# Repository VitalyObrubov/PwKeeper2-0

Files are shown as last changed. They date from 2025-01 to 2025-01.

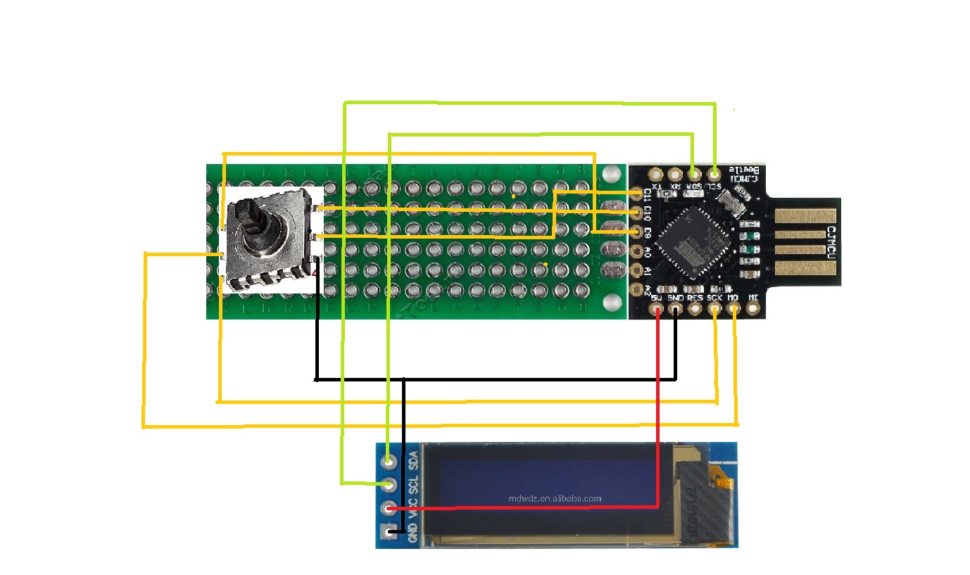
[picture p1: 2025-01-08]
PwKeeper-wiring.jpg

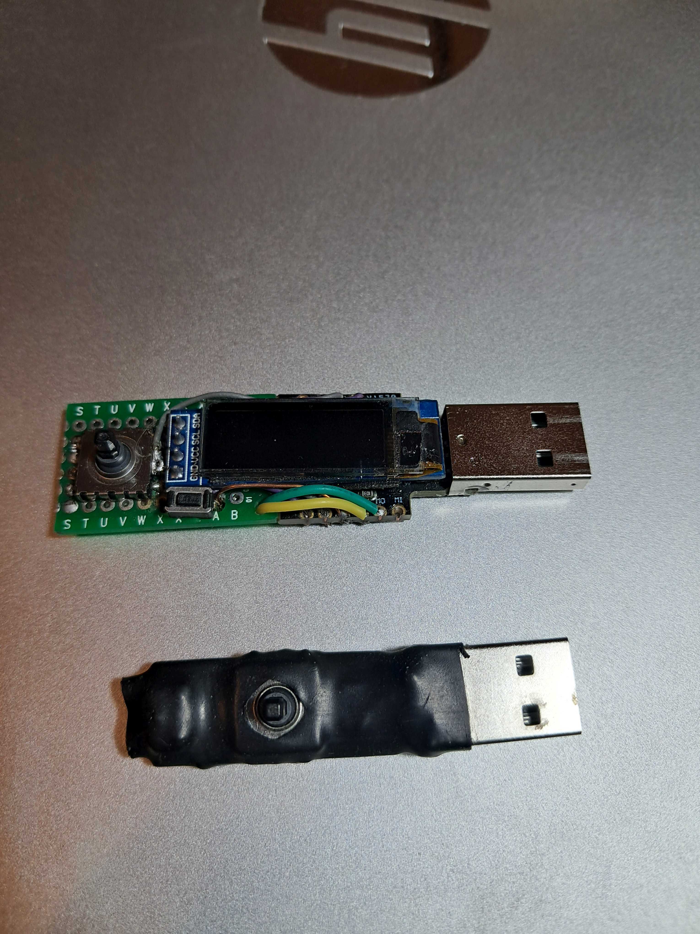
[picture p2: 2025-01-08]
PwKeeper-vs-MemType.jpg

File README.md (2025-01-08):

*****************   PasswordKeeper v2.0   ***********************

This is a simple hand made device for storing your passwords.
Essentially, it emulates USB keyboard and should work with any device where USB keyboard may be connected.
It sends user-defined sequences of keypresses as if they were entered from keyboard.
To simplify password management in token Windows program PwKeeperPC.exe is included into the package.
Also, serial console added to device. It allows config device from *nix systems.

------------------------------------------------------------------
How to write HEX to board:

1) Download and install software from arduino.cc
2) Connect your board to PC and install all necessary drivers.
3) Open DeviceManager window. Open COM and LPT node. There you should see you board as virtual COM port.
4) On Arduino board connect RST pin to GND.
5) In COM and LPT node new COM port should appear on ~8 sec. And then it replaced by port, which you have seen already.
   If you do not see new ports to appear try to repeat step 4, but connect RST to GND 2 times with interval of 1 sec between tries.
6) Replace COM16 in command in CMD file with port, which appears temporarily.
   Check pathes to AVRDUDE.EXE and avrdude.conf in command.
   Correct it according to your system.
7) Connect RST pin to GND. Start CMD and remove RST to GND connection.
   Download to board should pass.

Essentialy, COM port that you see when board is in idle state - it is HID port. It is not the LOADER port. Board LOADER COM appears only on short period after reset.
-------------------------------------------------------------------   

Changes history:
v2.0 - 08.01.2025
        - Forked & changed
	- Arduino Leonardo Beetle insted Leonardo-Pro-Micro-ATmega32U4
 - 4-way joistick insted 2 keys

v1.5 - 13.02.2018
        - Bugfix in login transmit procedure.

v1.4 - 24.11.2016
	- *nix-like TTY console added to PwKeeper
	- Commands description added to rtf.

v1.3 - 16.11.2016
	- Several bugfixes in PwKeeperPC.exe
	- Several bugfixes in PwKeeper.hex
 	- *.stl files added
	- Quick access buttons added to wiring diagram

v1.2 - 10.11.2016 
	- First public release

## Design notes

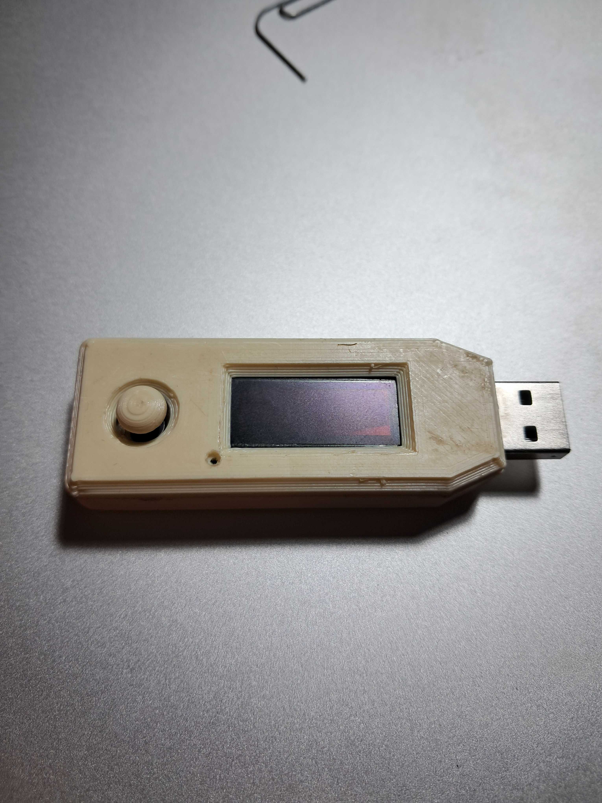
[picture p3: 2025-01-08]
PwKeeper-rdy-1.jpg

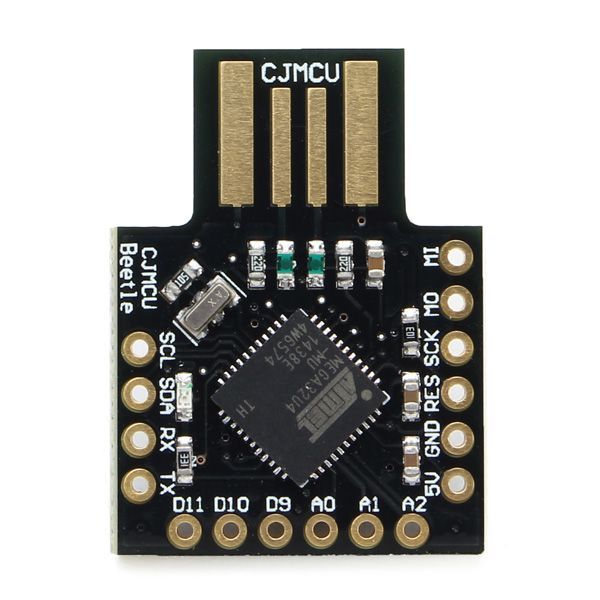
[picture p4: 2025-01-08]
Leonardo Beetle.jpg

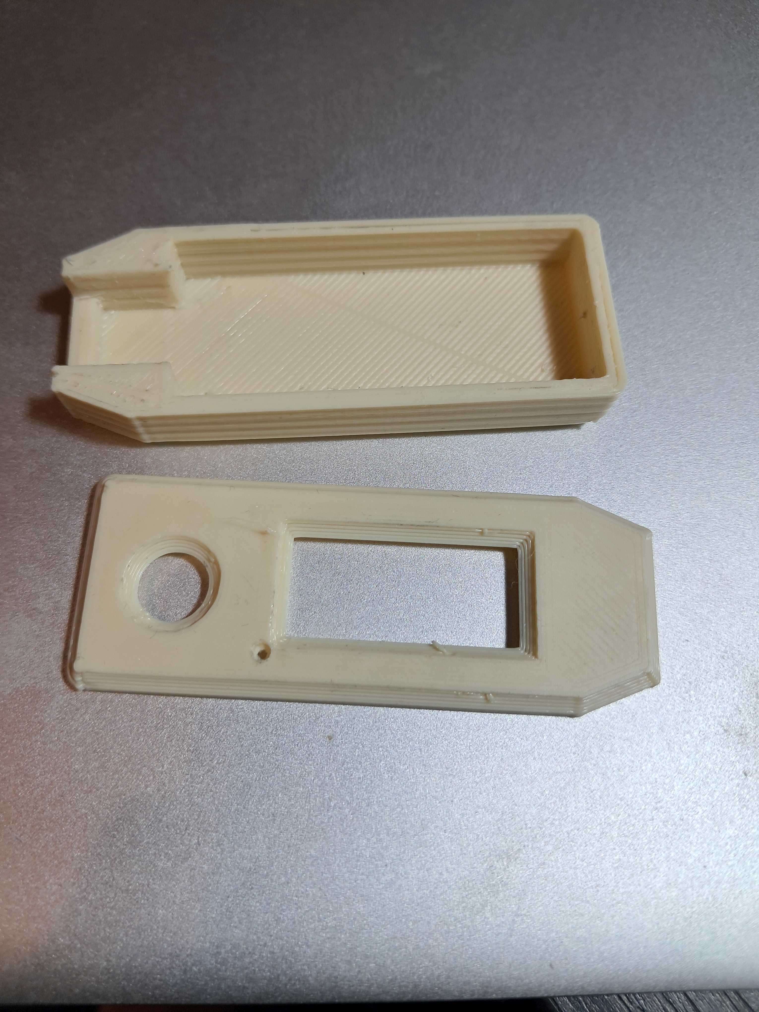
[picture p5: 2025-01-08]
PwKeeper-box.jpg

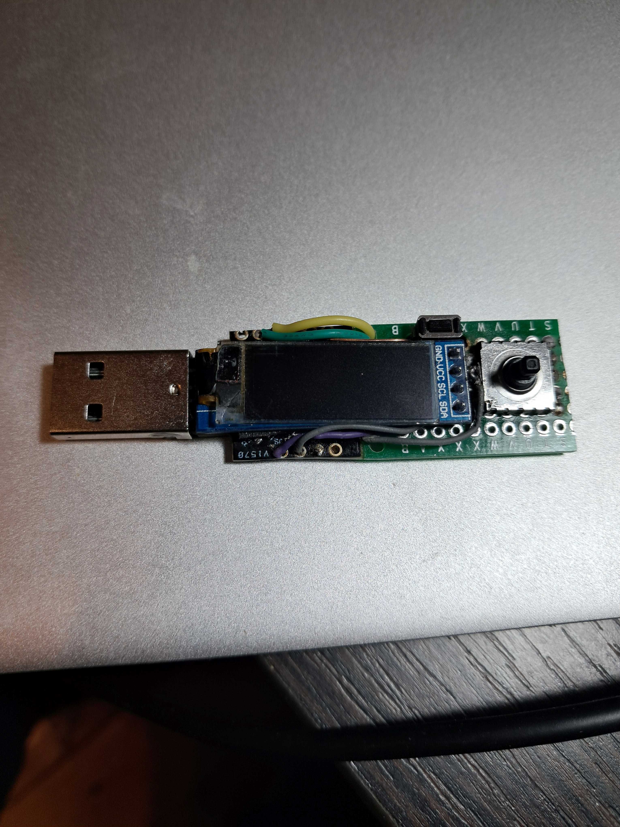
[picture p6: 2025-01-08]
PwKeeper-top.jpg

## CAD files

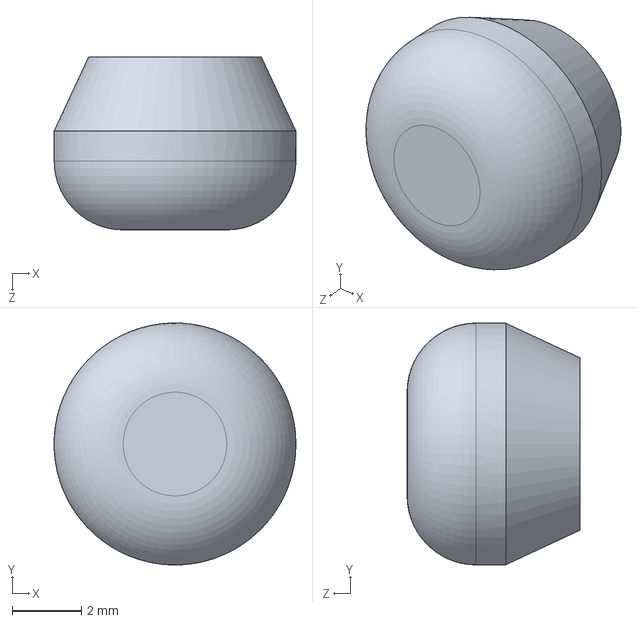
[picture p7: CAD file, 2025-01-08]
3D models/Knob.SLDPRT
7.00 x 7.00 x 5.00 mm

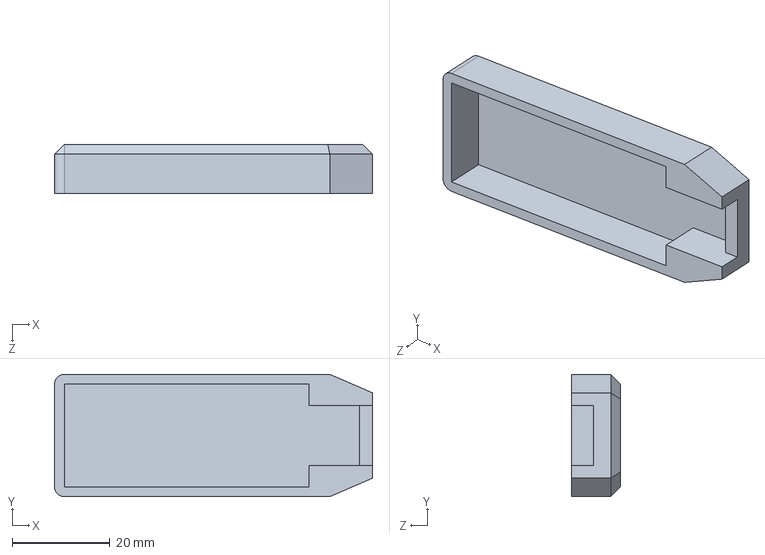
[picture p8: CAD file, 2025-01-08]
3D models/Case_bott.SLDPRT
65.0 x 25.0 x 10.0 mm

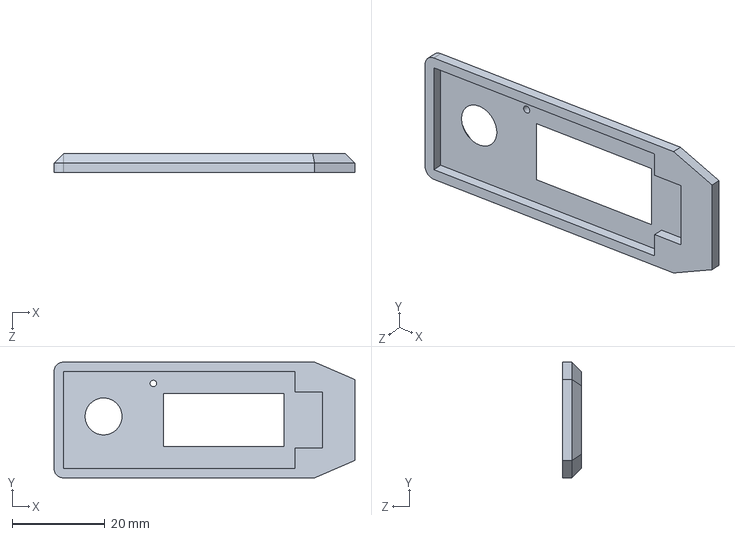
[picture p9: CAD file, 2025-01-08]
3D models/Case_top.SLDPRT
65.0 x 25.0 x 4.00 mm

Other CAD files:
3D models/Case_bott.STL
3D models/Case_top.STL
3D models/Knob.STL

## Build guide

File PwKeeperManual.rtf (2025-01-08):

Password Keeper v 2.00.
Описание: Ссылка1 (http://obruboff.ru/hardware-password-keeper/),

1. Структура меню устройства.

• Пароль
Если главный пароль не установлен, PwKeeper сразу переходит к Выбору
!!! Если вы забыли пароль – восстановить его нельзя, только стереть все данные в устройстве и сбросить пароль в пустой !!!
o Up, Down, Left, Right
Ввод символов пароля.
o OK => если пароль правильный переход к Выбору.
o Long Ok Переход на Сброс. – Если вы забыли пароль.
• Выбор записи
o Up, Down – движение по списку.
o Right, OK => Отправить пароль.
o Left, Long OK => Меню настроек устройства
• Меню настроек
o Left, Right – движение по меню.
USB – режим взаимодействия с PwKeeperPc
TTY – Консоль управления
PSW –Установить главный пароль
CLR – Переход на Сброс.
o Ok => выбор пункта.
o Long Ok, Left из крайнего => Выxoд
Если данные были изменены – переход на сохранение
• Сброс
o Up– Cтереть все данные в устройстве.
o Down – отказаться от сброса
• Сохранение данных
o Up– Записать новые данные.
o Down – отказаться от записи

2. Спецсимволы и макросы для управления кнопками

Кнопка | Нажать | Отпустить
KEY_LEFT_ALT | \a | \A
KEY_BACKSPACE | \b | \B
KEY_LEFT_CTRL | \c | \C
KEY_DELETE | \d | \D
KEY_ESC | \e | \E
KEY_RIGHT_SHIFT | \f | \F
KEY_RIGHT_ARROW | \g | \G
KEY_HOME | \h | \H
KEY_INSERT | \i | \I
KEY_CAPS_LOCK | \k | \K
KEY_LEFT_ARROW | \l | \L
KEY_END | \n | \N
KEY_PAGE_DOWN | \o | \O
KEY_PAGE_UP | \p | \P
KEY_RIGHT_ALT | \q | \Q
KEY_RETURN | \r | \R
KEY_LEFT_SHIFT | \s | \S
KEY_TAB | \t | \T
KEY_UP_ARROW | \u | \U
KEY_LEFT_GUI | \v | \V
KEY_DOWN_ARROW | \w | \W
KEY_RIGHT_GUI | \x | \X

Задержка на 300мс \z
Задержка на 1000мс \Z
Отпустить все кнопки \@
Последовательность \[….]

Например, Ctrl-Alt-Del можно записать как \c\a\v\z или как \[cavz]

Пример настроек для входа в систему:
Имя: Комп-Работа V1: \[cavz
Login: Ivanov_PS\t V5:\[zv]word\r
Пароль: Secret123\r

Пример настроек для входа в банк:
Имя: Сбер-Дебет
Login: 45978726234\t
Пароль: zzFFeerrr123\r

3. TTY - *NIX консоль управления

В firmware v1.04 добавлена консоль управления, специально для работы с устройством из *nix ОС. Эта консоль позволяет редактировать данные в PwKeeper с помощью нескольких команд, похожих по синтаксису на VI команды.
Для запуска консоли надо выбрать кнопками пункт меню “Device Menu”->”TTY”. После старта открывается виртуальный COM порт. К нему можно подсоединиться любой подходящей программой эмуляции терминала. В режиме TTY устройство отправляет обратно все введенные строки и отображает все поля текущей записи.

Команды:
? - Краткий справочник команд.
U - Переход на первую запись
D - Переход на последнюю запись
u - Переход на одну запись вверх
d - Переход на одну запись вниз
W - Установить главный пароль. Пароль состоит из символов:
u – Однократное нажатие вверх
U – Двукратное нажатие вверх
d – Однократное нажатие вниз
D – Двукратное нажатие вниз
uuDDUd = 2 up, 2 double down, 1 double up, 1 down
!!! Это опасная команда. Этот пароль будет всегда требоваться при включении!
A - Добавить новую запись
E - Удалить текущую запись
C - Установить поле Comment.
N - Установить поле Name.
P - Установить поле Password.
1-6 - Установить поля V1 – V6.
Примеры:
>WuuDd - Установить главный пароль: 2 single up, 1 double down, 1 single down.
>U - Перейти к первой записи
>CAOL-my - Установить отображаемый коментарий в “AOL-my”
>3 - Удалить поле V3
>1\[cavz - Установить поле V1 в Ctrl-Alt-Del + задержка 300 мс

4. Загрузка и работа
Для загрузки HEX в Arduino Pro Micro в проекте на GITHUB (https://github.com/Den-W/PwKeeper) есть файл LOAD_HEX.CMD.
1) Установить Arduino IDE (http://arduino.ru/Arduino_environment) и проверить путь к AVRDUDE.EXE и avrdude.conf. Исправьте пути в CMD в соответствии с Вашей системой.
!!! Важно!!! Если путь содержит пробелы, не забудьте обрамить его кавычками “ !
2) Откройте окно DeviceManager. Откройте COM and LPT узел.
3) Подключите Arduino Pro Micro к USB или замкните RST пин на GND 2 раза с интервалом около 1 сек.
4) В устройствах COM and LPT появится новый COM порт. И через ~8 сек он поменяется на другой, который будет виден пока устройство подключено.
Замените COM16 в команде на порт, который появлялся первым, а не на тот, что виден всегда!
5) После того, как в CMD файл внесены изменения повторите процедуру сброса или подсоедините плату к компу заново. Пока виден “исчезающий” COM порт запустите LOAD_HEX.CMD.
Загрузка должна пройти. Вы увидите на экране 0\0 и мигающую точку – значит все работает.

PwKeeperPc:
Для соединения с PwKeeperPc вам нужно перейти в МенюНастроек.
Для этого при первом включении выполните долгое нажатие кнопки Вниз, выберите пункт USB и 2 раза или долго нажмите на верхнюю кнопку.
Появится надпись USB: 0\0.
После этого можно нажимать кнопки Чтение\Запись на PwKeeperPC. Программа PwKeeperPc видит токен только в этом режиме.

Unix\Serial console:
Для соединения в командном режиме вам нужно перейти в МенюНастроек.
Для этого при первом включении выполните долгое нажатие кнопки Вниз, выберите пункт TTY и 2 раза или долго нажмите на верхнюю кнопку.
Появится надпись TTY: 0\0.
Далее запустите какую-либо программу терминала. В Arduino IDE можно использовать встроенную консоль (Ctrl-Shift-M). Используя VI-подобные команды из параграфа 3 можно редактировать данные в токене.

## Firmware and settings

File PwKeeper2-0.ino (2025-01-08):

#include <Arduino.h>
#include <stdio.h>
#include <EEPROM.h>
#include <U8glib.h>
#include <Keyboard.h>
#include "OneButton.h"
#include <avr/pgmspace.h>

#define  PIN_BTN_UP       9      // Button UP
#define  PIN_BTN_DN       15     // Button DOWN
#define  PIN_BTN_LEFT     16      // Button LEFT
#define  PIN_BTN_RIGHT    11     // Button RIGHT
#define  PIN_BTN_OK       10      // Button OK

#define  RXLED            17      // RX led pin

//                        0x01-0x0E - Fast key access    
#define  BTN_UP           0x20    // UP
#define  BTN_DOWN         0x21    // DOWN
#define  BTN_ENT          0x22    // Enter == DoubleUp
#define  BTN_ESC          0x23    // Esc == DoubleDown
#define  BTN_INS          0x24    // Ins == LongUp
#define  BTN_DEL          0x25    // Del = LongDown

#define  BTN_LEFT          0x26    // Left
#define  BTN_RIGHT         0x27    // Right
#define  BTN_OK            0x28    // Ok
#define  BTN_MENU          0x29    // Menu == LongOk


#define  MAX_DATA         1000    // Max data size
#define  MAX_PASSWORD     20      // Max password length
#define  MAX_BUFFER       128     // Max IO size
#define  MAX_EDIT         64      // EditStr size. <= MAX_BUFFER

#define  VERSION       	  "1.5"   // Version string

typedef unsigned long DWORD;

/*
 START
 * RESET - LongPressDOWN
 * PASSWORD - Enter password   
   * SELECT - Up, Down
     * SendPassword - Enter, Ins
     * SelectRecord - Up, Down
     * ConfigMenu   - Del
       * M_CFG_USB
       * M_CFG_PASSW
       * M_CFG_RESET
     * EditRecord   - Esc
       * Select Tag - Up, Down
       * Return     - Esc
       * EditTag    - Enter
         * Select Char - Up, Down
         * Edit char   - Enter, Ins
         * Return      - Esc     
 */

class CGlobalData
{   
  public:
    typedef   void (*pFUNC)( void );    
    
    byte    _St;
    byte      mPassword[MAX_PASSWORD];// 0x20:Up, 0x10:Double, 0x0F:ClickN
    byte      mData[MAX_DATA];  // EEProm data. 00:Nothing, 01:ShowName, 02:SendName, 03:SendPassw, 04:SendCite
    byte    _Wr;                // Data between _St and _Wr stored in flash memory. _Wr == crc8 of block
        
    byte      mChanged;         // mData changed    
    byte      mIsPw;            // Password checked
    short     mRecOffset;       // Record ofset in mData
    byte      mKey;             // Pressed key
    byte      mKeyUpLp;         // In key UP LongPress
    byte      mKeyDnLp;         // In key Dn LongPress
    byte      mPosMenu;         // current selected item
    byte      mPosEdit;         // Position in mEditStr
    byte      mPass;            // loop() pass counter
    byte      mWaitKey;         // Wait key before call to proc
    byte      mRecCur;          // Current Record No
    byte      mRecAll;          // Total Record count
    short     mUsbRx;           // Usb RXed data
    short     mUsbTx;           // Usb TXed data
    long      mIdleTo;
    char      mEditStr[MAX_BUFFER];// Edit buffer for value correction    
    byte    _En;
    
    OneButton mBtUp, mBtDn, mBtLeft, mBtRight, mBtOk;     // Button handlers
    pFUNC     mpfRun, mpfRunPrev;
    pFUNC     mpfDisp, mpfDispPrev;

    CGlobalData() : mpfRun(0), mpfRunPrev(0), mpfDisp(0), mpfDispPrev(0),
                    mBtUp( PIN_BTN_UP, true), mBtDn( PIN_BTN_DN, true),
                    mBtLeft( PIN_BTN_LEFT, true), mBtRight( PIN_BTN_RIGHT, true),
                    mBtOk( PIN_BTN_OK, true)
    { memset( &_St, 0, &_En-&_St );      
    }

    void  SetFunc( pFUNC fRun, pFUNC fDisp ) 
          {   if( !fRun ) 
              {  mpfRun = mpfRunPrev; 
              } else 
              {  mpfRunPrev = mpfRun; 
                 mpfRun = fRun;                
              }
              if( !fDisp ) mpfDisp = mpfDispPrev; 
              else {  mpfDispPrev = mpfDisp; 
                      mpfDisp = fDisp; 
              }              
          }
    void  Start(void);
    void  Run(void);
    void  Draw(void); 
    void  FlashRd(void);
    void  FlashWr(void);
    void  SetRecCntr( void );
    void  DrawUsb( const char *Pfx );
    void  DrawYN( const __FlashStringHelper *Msg );
    void  DrawLabels( const __FlashStringHelper *UpStr, const __FlashStringHelper *DnStr );
    void  PrnPrm( int PosN, int X, const __FlashStringHelper *Name );
    void  SerTx( int TxSz, const void *Tx, char *Hdr=0 );
    int   GetFastButton( void );
    int   GetLine( void );
    int   DelCurRec( void );

    static void  fStart(void);  // Start point
    static void  fPassword(void); static void  fDispPassword(void);   // Enter&check main password
    static void  fReset(void);    static void  fDispReset(void);      // Reset all Yes/No?
    static void  fSelect(void);   static void  fDispSelect(void);     // Select record
    static void  fRecMenu(void);  static void  fDispRecMenu(void);    // Select Record tag
    static void  fRecTagPos(void);static void  fDispRecTagPos(void);  // Select position in tag
    static void  fRecTagEdt(void);static void  fDispRecTagEdt(void);  // Edit char in tag
    static void  fRecDel(void);   static void  fDispRecDel(void);     // Delete record Yes\No?
    static void  fRecSave(void);  static void  fDispRecSave(void);    // Save changes Yas\No?
    static void  fCfgMenu(void);  static void  fDispCfgMenu(void);    // Config menu
    static void  fCfgPwd(void);   static void  fDispCfgPwd(void);     // Get new password
    static void  fCfgPwd2(void);  static void  fDispCfgPwd2(void);    // Repeat new password & set
    static void  fUsbIo(void);    static void  fDispUsbIo(void);      // External control
    static void  fTty(void);      static void  fDispTty(void);        // External TTY console
        
    void  SetEditStr( void );
    int   PwdEnter( void );
    void  KbdSend( void );
    void  Defaults( void )
          { memset( &_St, 0, &_En-&_St );
            FlashWr();
          }    
};

static CGlobalData gD;
U8GLIB_SSD1306_128X32 u8g(U8G_I2C_OPT_DEV_0|U8G_I2C_OPT_NO_ACK|U8G_I2C_OPT_FAST);  // Fast I2C / TWI 
const byte PinNoFast[] = { 4,5,6,7,8,18,19,20,21,0 };

//-----------------------------------------------------------------------------

void setup(void) 
{ gD.Start();
}

void loop(void) 
{ gD.Run();
}

// Button handlers
void hBtUpSingle()  
  { gD.mKey = BTN_UP; 
    }
void hBtUpDouble()  
  { gD.mKey = BTN_ENT;  
    }
void hBtUpLongSt()  
  { gD.mKeyUpLp = 1; gD.mKey = BTN_INS; 
    }
 void hBtUpLongEnd() 
 { gD.mKeyUpLp = 0; 
  }

void hBtDnSingle()  
  { gD.mKey = BTN_DOWN; 
    }
void hBtDnDouble()  
  { gD.mKey = BTN_ESC; 
   }
void hBtDnLongSt()  
  { gD.mKeyDnLp = 1; gD.mKey = BTN_DEL; 
    }
 void hBtDnLongEnd() 
 { gD.mKeyDnLp = 0; 
 }

void hBtLeftSingle()   
  { gD.mKey = BTN_LEFT; 
    }
void hBtRightSingle() 
  { gD.mKey = BTN_RIGHT; 
    }
void hBtOkSingle()    
  { gD.mKey = BTN_OK; 
    }
void hBtOkLongSt()  
  { gD.mKeyDnLp = 1; gD.mKey = BTN_MENU; 
    }
 void hBtOkLongEnd() 
 { gD.mKeyDnLp = 0; 
 }

//-----------------------------------------------------------------------------

int   CGlobalData::GetFastButton( void )
{ int i, n;

  for( i=0; PinNoFast[i]; i++ )
   if( LOW == digitalRead( PinNoFast[i] ) ) break;   // read the input pin

  if( !PinNoFast[i] ) return 0;
  
  for( n=0; n<10; n++ )
  { delay( 50 );
    if( LOW != digitalRead( PinNoFast[i] ) ) break;   // read the input pin
  }
  
  if( n < 4 ) return 0;
  if( n < 8 ) return i+1;   
  
  return (i+1) | 0x10;   
}

//-----------------------------------------------------------------------------

void  CGlobalData::Start(void) 
{ FlashRd();  // Read data from eeprom
  mIdleTo = millis();
  Serial.begin( 115200 );

  for( int i=0; PinNoFast[i]; i++ )
   pinMode( PinNoFast[i], INPUT_PULLUP ); // set pin to input  

  pinMode(RXLED, OUTPUT);  // Set RX LED as an output
  
  // flip screen, if required
  //u8g.setRot180();
  u8g.setColorIndex(1);

  mBtUp.setClickTicks( 300 );
  mBtDn.setClickTicks( 300 );
  mBtLeft.setClickTicks( 300 );
  mBtRight.setClickTicks( 300 );
  mBtOk.setClickTicks( 300 );
  
  mBtUp.attachClick( hBtUpSingle );
  mBtUp.attachDoubleClick( hBtUpDouble );
  mBtUp.attachLongPressStart( hBtUpLongSt );
  mBtUp.attachLongPressStop( hBtUpLongEnd );
  
  mBtDn.attachClick( hBtDnSingle );
  mBtDn.attachDoubleClick( hBtDnDouble );
  mBtDn.attachLongPressStart( hBtDnLongSt );
  mBtDn.attachLongPressStop( hBtDnLongEnd );
  
  mBtLeft.attachClick( hBtLeftSingle );
  mBtRight.attachClick( hBtRightSingle );
  
  mBtOk.attachClick( hBtOkSingle );
  mBtOk.attachLongPressStart( hBtOkLongSt );
  mBtOk.attachLongPressStop( hBtOkLongEnd );

  mWaitKey = 0;
  SetFunc( fStart, 0 );
  SetRecCntr();
}

//-----------------------------------------------------------------------------

void  CGlobalData::Run(void) 
{ mPass++;
  mKey = 0;
  mBtUp.tick();
  mBtDn.tick();
  mBtLeft.tick();
  mBtRight.tick();
  mBtOk.tick();

  if( mKey ) mIdleTo = millis();
  if( millis() - mIdleTo > 600*1000L ) 
  { mWaitKey = 0;
    SetFunc( fStart, 0 );
  }

  while( mpfRun )
  { if( mWaitKey && !mKey ) 
    { if( mpfRun != fSelect ) break;
      mKey = GetFastButton();
      if( !mKey ) break;
    }
    mWaitKey = 1;
    mpfRun();
    break;
  }
  
  // picture loop
  u8g.firstPage();  
  do 
  { u8g.setFont( u8g_font_9x18B );
    if( mPass & 0x10 ) u8g.drawBox( 126, 30, 2, 2 ); // Flasher
    if( mpfDisp ) mpfDisp();
  } while( u8g.nextPage() );
}

//-----------------------------------------------------------------------------

void CGlobalData::fStart(void)
{ TXLED0;
  digitalWrite(RXLED, HIGH);
  gD.mPosEdit = 0;
  gD.mIdleTo = millis();
  memset( gD.mEditStr, 0, sizeof(gD.mEditStr) );

  for( int i=0; i < MAX_PASSWORD; i++ )
  { if( gD.mPassword[i] == 0 ) continue;
    gD.SetFunc( gD.fPassword, gD.fDispPassword );
    return;
  }
  gD.SetFunc( gD.fSelect, gD.fDispSelect ); // Password == NULL
}

//-----------------------------------------------------------------------------

void CGlobalData::fPassword(void)
{ int   i = gD.PwdEnter();

  if( !i ) return;
  if( i < 0 )
  { gD.SetFunc( gD.fReset, gD.fDispReset );
    return;
  }

  if( memcmp( gD.mPassword, gD.mEditStr, MAX_PASSWORD ) ) 
  { gD.mWaitKey = 0;
    gD.SetFunc( gD.fStart, 0 ); // Passw bad, restart
    return;
  }
  gD.SetFunc( gD.fSelect, gD.fDispSelect ); // Password Ok
}

void CGlobalData::
fDispPassword(void)
{ int   i, n, x, y;
  char  Tb[MAX_PASSWORD+2];

  u8g.drawStr( 20, 13, F("Password?") );
  u8g.setFont(u8g_font_6x12r);
  u8g.drawStr( 110, 7, F(VERSION) ); 
    
  for( i=0; i<MAX_PASSWORD; i++ )
  { n = gD.mEditStr[i];        
    Tb[i] = '0' | (n & 0x0F);

    if ( gD.mPosEdit == i )
    //if( n )
    { x = i*6+1;
      y = n & 0x20 ? 19:29;
      if( n & 0x10 ) u8g.drawBox( x, y+1, 3, 2 );
      else u8g.drawLine( x, y, x+3, y );
    }
  }
  Tb[MAX_PASSWORD] = 0;
  u8g.drawStr( 0, 28, Tb );
}

//-----------------------------------------------------------------------------

void CGlobalData::fReset(void)
{  switch( gD.mKey )
  {  case BTN_ENT:
     case BTN_OK:
     case BTN_INS:
        gD.Defaults();
        gD.SetFunc( gD.fStart, 0 );
        break;
     case BTN_LEFT:
     case BTN_DOWN:
     case BTN_ESC:
     case BTN_DEL:
        gD.SetFunc( 0, 0 );
  }
}

void CGlobalData::fDispReset(void)
{ gD.DrawYN( F("Clear all?") );  
}

//-----------------------------------------------------------------------------

void CGlobalData::fSelect(void)
{ int   i, n;
  // Serial.print("fSelect gD.mKey ");
  // Serial.println(gD.mKey, HEX);
  switch( gD.mKey )
  {  case BTN_UP:
        for( i = gD.mRecOffset-1; i >= 0; i-- )
        { if( gD.mData[i] != 0x01 ) continue;
          gD.mRecOffset = i;
          gD.SetRecCntr();
          break;
        }
        break;
     case BTN_DOWN:
        if( !gD.mData[gD.mRecOffset] ) break; // End of record
        for( i = gD.mRecOffset+1; i < sizeof(gD.mData); i++ )
        { if( gD.mData[i] && gD.mData[i] != 0x01 ) continue;
          gD.mRecOffset = i;
          gD.SetRecCntr();
          break;
        }
        break;
     case BTN_OK:
     case BTN_RIGHT:
        gD.KbdSend(); // Send password
        break;    
    //  case BTN_ESC: //Edit record
    //     gD.mChanged = 0;
    //     gD.mPosMenu = 0;            
    //     gD.SetFunc( gD.fRecMenu, gD.fDispRecMenu );
    //     break;
     case BTN_MENU:
     case BTN_LEFT: //Settings
        gD.mPosMenu = 0;
        memset( gD.mEditStr, 0, sizeof(gD.mEditStr) );
        gD.SetFunc( gD.fCfgMenu, gD.fDispCfgMenu );
        return;
        
     default: // mKey == RecordNo     
        for( i=n=gD.mRecOffset=0; gD.mRecOffset < sizeof(gD.mData); gD.mRecOffset++ )
        { switch( gD.mData[gD.mRecOffset] )
          { default: continue;
            case 0x01:
              i = gD.mRecOffset;
              if( ++n != (gD.mKey&0x0F) ) continue;
              if( gD.mKey & 0x10 ) gD.KbdSend();
              break;
            case 0x00:
              gD.mRecOffset = i;
              break;
          }
          gD.SetRecCntr();
          return;
        }
  }
}

void CGlobalData::fDispSelect(void)
{   int i = gD.mRecOffset, n = 0, x;
    char  Tb[16];

    memset( gD.mEditStr, 0, sizeof(gD.mEditStr) );
    if( gD.mData[i] ) 
    { for( i++; i<sizeof(gD.mData); i++ )
      { x = gD.mData[i] & 0x0FF;        
        if( x <= 0x01 ) break;
        if( x < 0x0A ) n = MAX_EDIT+1;
        if( n < MAX_EDIT )
          gD.mEditStr[n++] = x;
      }
      if( x ) u8g.drawBox( 121, 30, 4, 2 );
    }
    gD.mEditStr[32] = 0;
    u8g.drawStr( 0, 19, gD.mEditStr );
    if( gD.mRecOffset ) u8g.drawBox( 121, 0, 4, 2 );
    u8g.setFont(u8g_font_6x12r);
    sprintf( Tb, "%d/%d", gD.mRecCur, gD.mRecAll );
    u8g.drawStr( 0, 30, Tb ); 
}

//-----------------------------------------------------------------------------

void CGlobalData::fRecMenu(void)
{ switch( gD.mKey )
  {  case BTN_UP:
        if( ++gD.mPosMenu > 3 ) gD.mPosMenu = 0;
        gD.SetEditStr();
        break;
     case BTN_DOWN:
        if( --gD.mPosMenu > 3 ) gD.mPosMenu = 3;
        gD.SetEditStr();
        break;
     case BTN_INS:
     case BTN_ENT:
        if( gD.mPosMenu == 3 ) 
        { gD.SetFunc( gD.fRecDel, gD.fDispRecDel ); 
          break;
        }        
        gD.mPosEdit = 0;
        gD.SetFunc( gD.fRecTagPos, gD.fDispRecTagPos );
        break;
     case BTN_DEL:
     case BTN_ESC:
        if( !gD.mChanged ) gD.SetFunc( gD.fSelect, gD.fDispSelect );
        else gD.SetFunc( gD.fRecSave, gD.fDispRecSave );
        break;
  }
}

void CGlobalData::fDispRecMenu(void)
{   int i = gD.mPosEdit > 13  ? gD.mPosEdit-13:0;
    u8g.drawStr( 1, 13, gD.mEditStr+i );

    u8g.setFont(u8g_font_6x12r);
    gD.PrnPrm( 0,  0, F("Show") );
    gD.PrnPrm( 1, 32, F("Name") );
    gD.PrnPrm( 2, 64, F("Pass") );
    gD.PrnPrm( 3, 96, F("DEL!") );
}

//-----------------------------------------------------------------------------

void CGlobalData::fRecTagPos(void)
{ int   i, n;
  byte  b;

  switch( gD.mKey )
  {  case BTN_UP:
        if( gD.mPosEdit >= MAX_EDIT-1 ) break;
        if( gD.mEditStr[gD.mPosEdit] ) gD.mPosEdit++;
        else gD.mEditStr[gD.mPosEdit+1] = 0;
        break;
     case BTN_DOWN:
        if( --gD.mPosEdit > MAX_EDIT ) gD.mPosEdit = strlen(gD.mEditStr);
        break;
     case BTN_INS:
     case BTN_ENT:
        gD.SetFunc( gD.fRecTagEdt, gD.fDispRecTagEdt );
        break;
     case BTN_ESC:      
        gD.mPosEdit = 0;
        gD.SetFunc( gD.fRecMenu, gD.fDispRecMenu );        

        i = gD.mRecOffset;
        for( ; i < sizeof(gD.mData); i++ )
        { b = gD.mData[i];
          if( !b ) break;
          if( b != gD.mPosMenu+1 ) 
          { if( b == 0x01 ) break;
            continue;
          }          
          for( n = i+1; n < sizeof(gD.mData); n++ ) 
          { b = gD.mData[n];
            if( b <= 0x01 ) break;
          }
          if( n < sizeof(gD.mData) )
            memcpy( gD.mData+i, gD.mData+n, sizeof(gD.mData)-n );
          break;
        }
        n = strlen( gD.mEditStr )+1;
        if( i+n > sizeof(gD.mData) ) n = sizeof(gD.mData) - i;
        if( n > 0 ) memmove( gD.mData+i+n, gD.mData+i, sizeof(gD.mData)-(i+n) );
        gD.mData[i++] = gD.mPosMenu+1;
        memcpy( gD.mData+i, gD.mEditStr, n-1 );
        break;
     case BTN_DEL:
        gD.mPosEdit = 0;
        gD.SetFunc( 0, 0 );
        break;
  }
}

void CGlobalData::fDispRecTagPos(void)
{ int i = gD.mPosEdit > 13 ? 13:gD.mPosEdit;
  u8g.drawFrame( i*9, 0, 11, 16 );
  gD.fDispRecMenu();
}

//-----------------------------------------------------------------------------

void CGlobalData::fRecTagEdt(void)
{ byte  c;
  int   i, n;

  switch( gD.mKey )
  {  case BTN_UP:
        c = gD.mEditStr[gD.mPosEdit] + 1;
        if( c < ' ' ) c = ' ';
        else if( c > 0xFF ) c = ' ';
             else if( c == 0x7F ) c = 0xC0;
        gD.mEditStr[gD.mPosEdit] = c;
        gD.mChanged = 1;
        break;
     case BTN_DOWN:
        c = gD.mEditStr[gD.mPosEdit] - 1;
        if( c < ' ' ) c = 0xFF;
        else if( c == 0xBF ) c = 0x7E;            
        gD.mEditStr[gD.mPosEdit] = c;
        gD.mChanged = 1;
        break;
     case BTN_INS:
        if( gD.mPosEdit >= MAX_EDIT-1 ) break;
        i = strlen( gD.mEditStr );
        if( i >= MAX_EDIT-1 ) i = MAX_EDIT-1;
        i -= gD.mPosEdit;
        if( i > 0 ) memmove( gD.mEditStr+gD.mPosEdit+1, gD.mEditStr+gD.mPosEdit, i );
        gD.mEditStr[gD.mPosEdit] = 'A';
        gD.mChanged = 1;
        break;
     case BTN_DEL:
        strcpy( gD.mEditStr+gD.mPosEdit, gD.mEditStr+gD.mPosEdit+1 );
        gD.mChanged = 1;
        break;
     case BTN_ENT:
     case BTN_ESC:      
        gD.SetFunc( gD.fRecTagPos, gD.fDispRecTagPos );
        break;
  }
}

void CGlobalData::fDispRecTagEdt(void)
{   if( gD.mPass & 0x10 ) 
    { int i = gD.mPosEdit > 13 ? 13:gD.mPosEdit;
      u8g.drawFrame( i*9, 0, 11, 16 );
    }
    gD.fDispRecMenu();
}

//-----------------------------------------------------------------------------

void CGlobalData::fRecSave(void)
{ switch( gD.mKey )
  {  case BTN_UP:
        gD.FlashWr();
        break;
     case BTN_DOWN:
        gD.mChanged = 0;
        gD.FlashRd();
        break;
     default:
        return;
  }
  gD.SetRecCntr();
  gD.SetFunc( gD.fSelect, gD.fDispSelect );
}

void CGlobalData::fDispRecSave(void)
{   gD.DrawYN( F("Save changes?") );      
}

//-----------------------------------------------------------------------------

void CGlobalData::fRecDel(void)
{ switch( gD.mKey )
  {  case BTN_ENT:
     case BTN_INS:
        if( !gD.DelCurRec() ) break;        
     case BTN_DOWN:
     case BTN_ESC:
     case BTN_DEL:      
        gD.SetFunc( gD.fRecMenu, gD.fDispRecMenu );
        break;
  }
}

void CGlobalData::fDispRecDel(void)
{ u8g.drawStr( 0, 20, gD.mEditStr );
  gD.DrawYN( F("Delete record?") );  
}

int  CGlobalData::DelCurRec(void)
{ int i, n;

  if( !gD.mData[gD.mRecOffset] ) return 0;
  for( i = gD.mRecOffset+1; gD.mData[i]>0x01 && i<sizeof(gD.mData); i++ );
  n = sizeof(gD.mData) - i;
  if( n <= 0 ) return 0;
  memcpy( gD.mData+gD.mRecOffset, gD.mData+i, n );
  memset( gD.mData+gD.mRecOffset+n, 0, sizeof(gD.mData)-(gD.mRecOffset+n) );
  gD.mChanged = 1;
  return 1;
}

//-----------------------------------------------------------------------------

void CGlobalData::fCfgMenu(void)
{ switch( gD.mKey )
  {  case BTN_RIGHT:
        if( ++gD.mPosMenu > 3 ) gD.mPosMenu = 0;
        break;
     case BTN_LEFT:
        if( --gD.mPosMenu > 3 ) //Exit
          { gD.mPosMenu = 3;
            if( !gD.mChanged ) gD.SetFunc( gD.fSelect, gD.fDispSelect );
            else gD.SetFunc( gD.fRecSave, gD.fDispRecSave );        
          }
        break;
     case BTN_OK:
        gD.mPosEdit = 0;
        switch( gD.mPosMenu )
        { case 0: // Enter USB exchange mode
            gD.mIsPw = 0;
            gD.mWaitKey = 0;
            gD.mUsbRx = gD.mUsbTx = 0;
            gD.SetFunc( gD.fUsbIo, gD.fDispUsbIo );
            break;
            
          case 1: // Enter TTY exchange mode
            gD.mWaitKey = 0;
            gD.mUsbRx = gD.mUsbTx = 0;
            gD.SetFunc( gD.fTty, gD.fDispTty );
            break;
            
          case 2:
            memset( gD.mEditStr, 0, sizeof(gD.mEditStr) );
            gD.SetFunc( gD.fCfgPwd, gD.fDispCfgPwd ); 
            break;
            
          case 3: 
            gD.SetFunc( gD.fReset, gD.fDispReset ); 
            break;
        }
        break;
     case BTN_MENU://Exit
     //case BTN_LEFT:
        if( !gD.mChanged ) gD.SetFunc( gD.fSelect, gD.fDispSelect );
        else gD.SetFunc( gD.fRecSave, gD.fDispRecSave );
        break;
  }
}

void CGlobalData::fDispCfgMenu(void)
{   u8g.drawStr( 1, 14, gD.mEditStr );
    u8g.setFont(u8g_font_6x12r);
    gD.PrnPrm( 0,  0, F("USB") );
    gD.PrnPrm( 1, 32, F("TTY") );
    gD.PrnPrm( 2, 64, F("Pass") );
    gD.PrnPrm( 3, 96, F("CLR!") );
}

//-----------------------------------------------------------------------------

void CGlobalData::fCfgPwd(void)
{ int i = gD.PwdEnter();
  if( i < 0 ) 
  { gD.SetFunc( gD.fCfgMenu, gD.fDispCfgMenu ); 
    return;
  }
  if( !i ) return;
  gD.mPosEdit = 0;
  memcpy( gD.mEditStr+32, gD.mEditStr, MAX_PASSWORD );
  memset( gD.mEditStr, 0, MAX_PASSWORD );
  gD.SetFunc( gD.fCfgPwd2, gD.fDispCfgPwd2 ); 
}

void CGlobalData::fDispCfgPwd(void)
{   gD.fDispPassword();
    u8g.setFont(u8g_font_6x12r);
    u8g.drawStr( 0, 7, F("New") );   
}

//-----------------------------------------------------------------------------

void CGlobalData::fCfgPwd2(void)
{ int i = gD.PwdEnter();
  if( i < 0 ) 
  { gD.SetFunc( gD.fCfgMenu, gD.fDispCfgMenu ); 
    return;
  }
  if( !i ) return;
  
  if( memcmp( gD.mEditStr+32, gD.mEditStr, MAX_PASSWORD ) ) 
  { gD.SetFunc( gD.fCfgMenu, gD.fDispCfgMenu ); 
    return;
  }
  gD.mChanged = 1;
  memcpy( gD.mPassword, gD.mEditStr, MAX_PASSWORD );
  gD.SetFunc( gD.fRecSave, gD.fDispRecSave );   
}
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
